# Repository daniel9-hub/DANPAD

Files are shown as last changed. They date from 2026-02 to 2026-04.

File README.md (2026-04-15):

# DANPAD
Hello, this is my submission for hackpad. I hope you'll like it :)
# Picture of the finished Hackpad


# Features
- 6 keys
- EC11 rotary encoder for volume adjusting
- 2 SK6812 MINI RGB LEDs
- a 3d printed case
# CAD Model
I made the model for the case in Onshape. It has 4 pieces: a bottom and mid plate(separated in case i needed to change
something so that i dont have to reprint the entire case), a top plate and a knob

Here is the case without electronics

# PCB
I made the pcb in KiCad. I used the image converter in KiCad for the pictures.
|Schematic|PCB|
|---|---|
|||
# Firmware
I wrote the code with KMK. The rotary encoder changes the volume and the keys do functions that i'm going to change according my needs.
# BOM
- 1x Seeed XIAO RP2040
- 6x MX-Style switches
- 6x Blank DSA keycaps
- 2x SK6812 MINI-E LEDs
- 1x EC11 Rotary encoder
- 4x M3x16mm screws
- 4x/8x M3x5mx4mm heatset inserts (i'm not sure how many i'll need)
- 1x 3d printed case
- 1x PCB
# Extra stuff
I might change the screw hole size on the case since i'm not sure how will the screws and heatset inserts fit. I also forgot to add a ground trace to the switches so I had to solder a wire to one of the switches right pin and connect it to the xiaos ground pin.

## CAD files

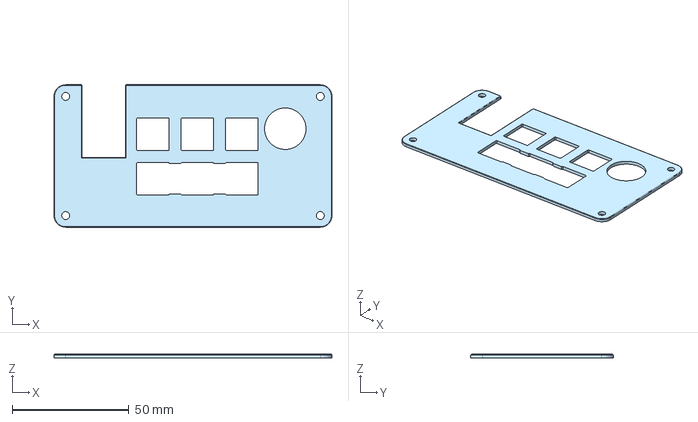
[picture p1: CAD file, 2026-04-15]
CAD/danpad top.step
119.0 x 61.0 x 1.50 mm

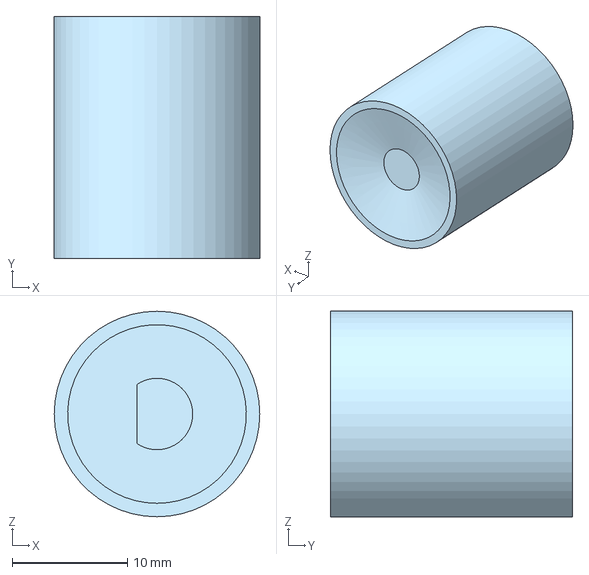
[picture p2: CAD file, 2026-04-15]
CAD/DANPAD WHEEL.step
17.8 x 21.0 x 17.8 mm

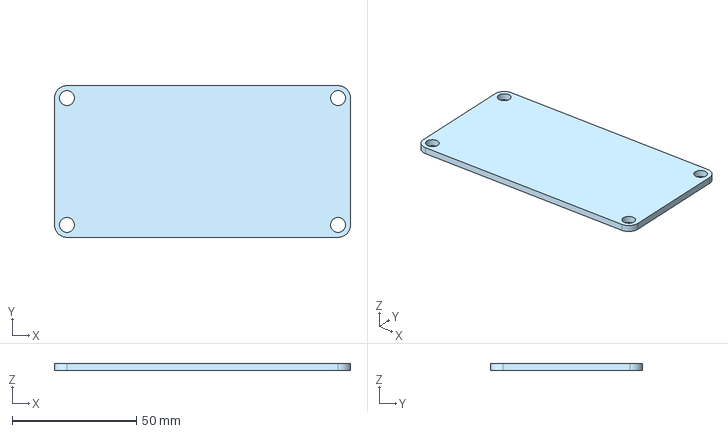
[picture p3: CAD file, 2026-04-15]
CAD/danpad bottom.step
119.0 x 61.0 x 3.00 mm

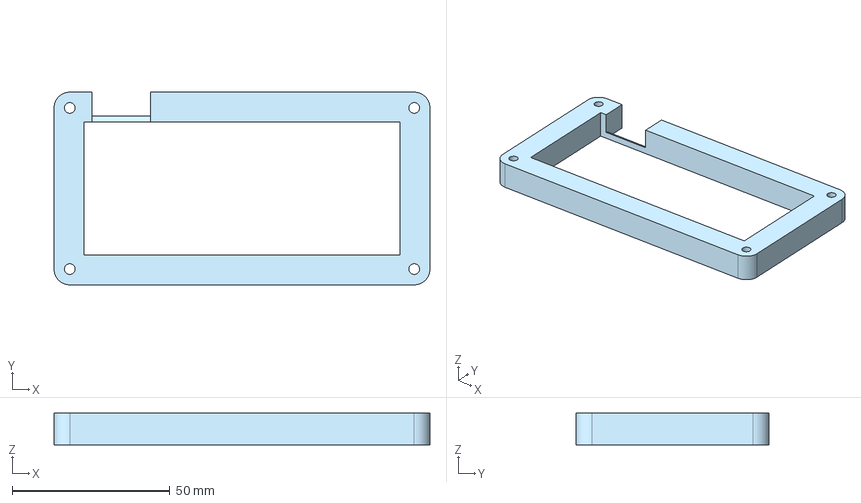
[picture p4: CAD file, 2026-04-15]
CAD/danpad middle.step
119.0 x 61.0 x 10.0 mm

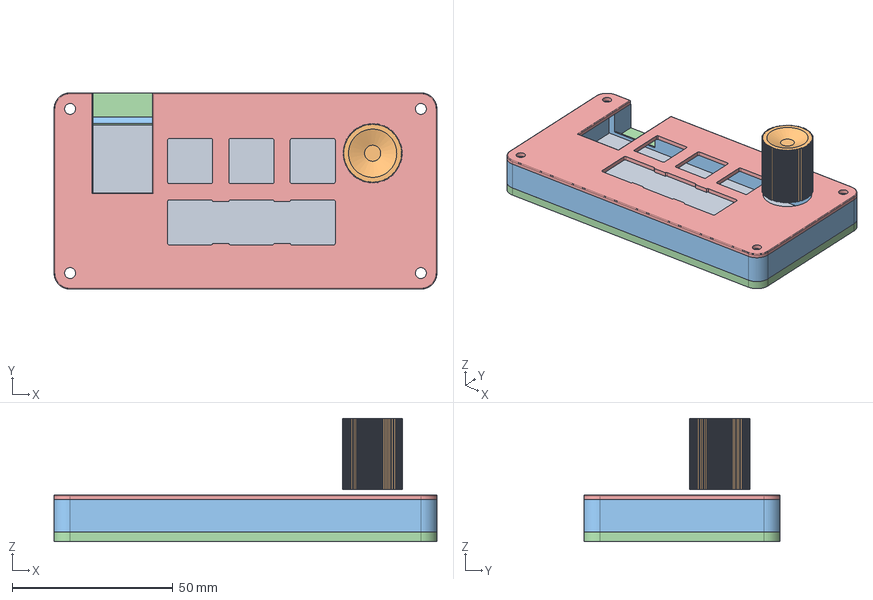
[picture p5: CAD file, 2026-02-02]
CAD/DANPAD hackpad.step
119.0 x 61.0 x 38.2 mm

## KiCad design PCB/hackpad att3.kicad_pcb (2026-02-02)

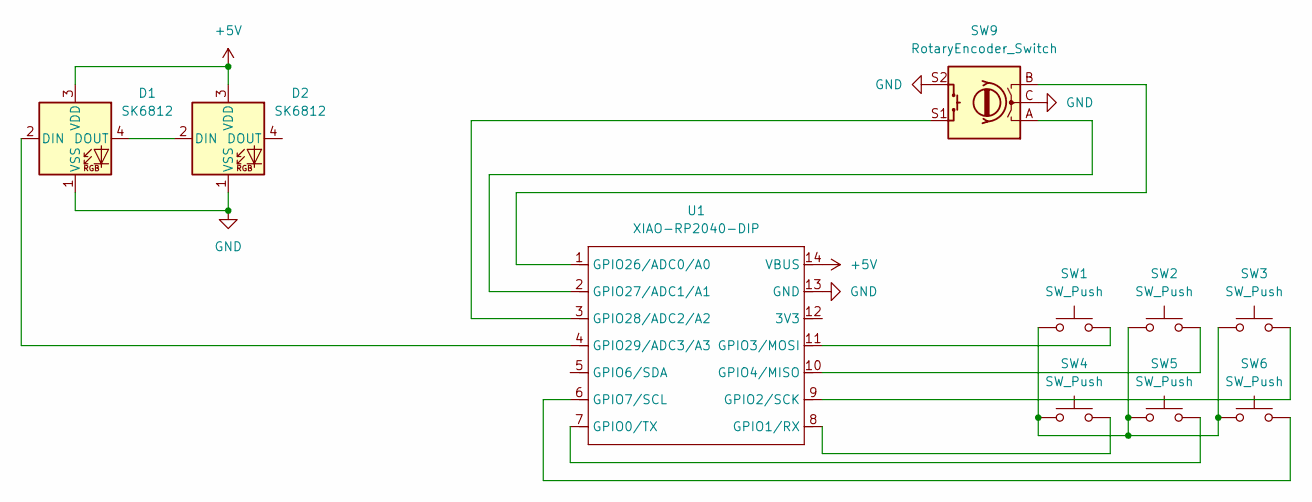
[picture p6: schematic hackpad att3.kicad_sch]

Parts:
D1, D2: SK6812; LED_SK6812MINI_PLCC4_3.5x3.5mm_P1.75mm
SW1, SW2, SW3, SW4, SW5, SW6: SW_Push; SW_Cherry_MX_1.00u_PCB
SW9: RotaryEncoder_Switch; RotaryEncoder_Alps_EC11E-Switch_Vertical_H20mm
U1: XIAO-RP2040-DIP

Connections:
+5V: D1.3 (VDD), D2.3 (VDD), U1.14 (VBUS)
GND: D1.1 (VSS), D2.1 (VSS), SW9.C, SW9.S2, U1.13 (GND)
unnamed: D1.2 (DIN), U1.4 (GPIO29/ADC3/A3)
unnamed: D1.4 (DOUT), D2.2 (DIN)
unnamed: SW1.1, SW2.1, SW3.1, SW4.1, SW5.1, SW6.1
unnamed: SW5.2, U1.7 (GPIO0/TX)
unnamed: SW4.2, U1.8 (GPIO1/RX)
unnamed: SW3.2, U1.9 (GPIO2/SCK)
unnamed: SW1.2, U1.11 (GPIO3/MOSI)
unnamed: SW2.2, U1.10 (GPIO4/MISO)
unnamed: SW6.2, U1.6 (GPIO7/SCL)
unnamed: SW9.B, U1.1 (GPIO26/ADC0/A0)
unnamed: SW9.A, U1.2 (GPIO27/ADC1/A1)
unnamed: SW9.S1, U1.3 (GPIO28/ADC2/A2)

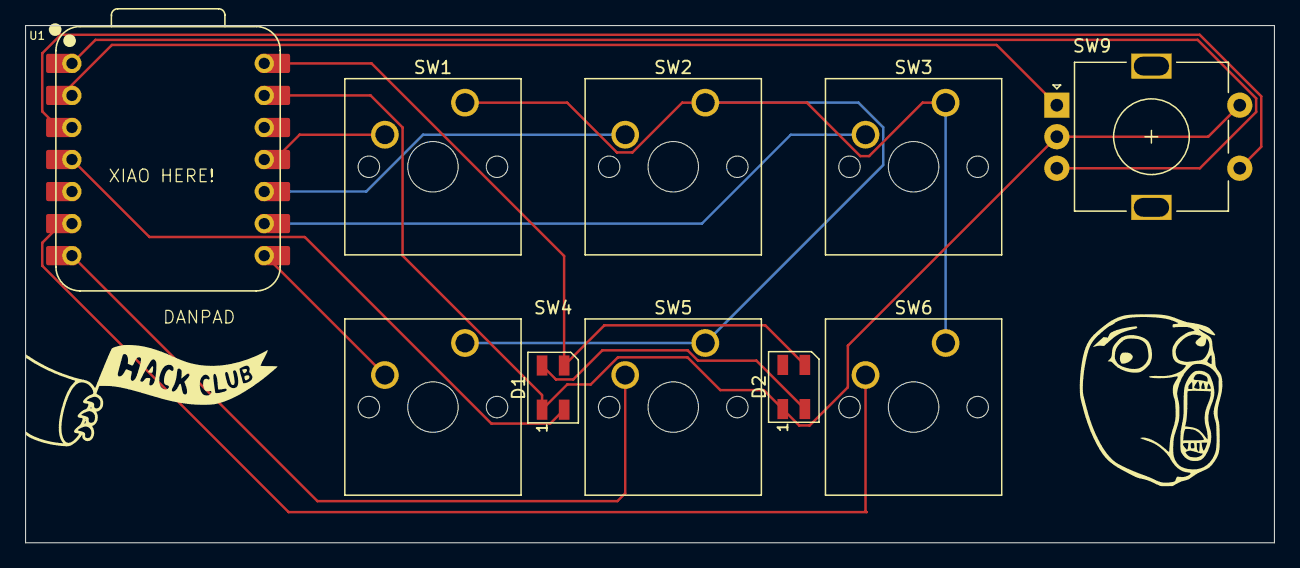
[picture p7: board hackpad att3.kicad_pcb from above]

Board: 2 copper layers, 99.0 x 41.0 mm, 10 parts (0 on the bottom side), 14 nets.

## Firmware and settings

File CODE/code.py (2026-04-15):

# main.py

print("Starting")

import board

from kmk.kmk_keyboard import KMKKeyboard
from kmk.keys import KC
from kmk.scanners.keypad import KeysScanner
from kmk.scanners import DiodeOrientation
from kmk.modules.macros import Macros
from kmk.modules.encoder import EncoderHandler
from kmk.extensions.rgb import RGB
keyboard = KMKKeyboard()
from kmk.extensions.media_keys import MediaKeys


macros = Macros()
keyboard.modules.append(macros)
encoder_handler = EncoderHandler()
keyboard.modules.append(encoder_handler)
keyboard.extensions.append(MediaKeys())



PINS = [board.GP3, board.GP4, board.GP2, board.GP1, board.GP0, board.GP7, board.GP28]


keyboard.matrix = KeysScanner(
    pins=PINS,
    value_when_pressed=False,
)



rgb = RGB(
    pixel_pin=board.GP29,
    num_pixels=2,
    rgb_order=(1, 0, 2),
    hue_default=100,
    sat_default=100,
    val_default=100,
    
)
keyboard.extensions.append(rgb)

encoder_handler.pins = ((board.GP27, board.GP26),) 


keyboard.keymap = [
    [KC.DELETE, KC.L, KC.SLASH, KC.C, KC.SPACE, KC.ENTER, KC.AUDIO_MUTE]
]

encoder_handler.map = [
    ((KC.AUDIO_VOL_UP, KC.AUDIO_VOL_DOWN),),
]

if __name__ == '__main__':
    keyboard.go()

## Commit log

2026-02-02 Add CAD folder
    [DANPAD hackpad.step]
2026-02-02 Add PCB folder
    [hackpad att3.kicad_pcb, hackpad att3.kicad_sch]
2026-04-15 Updated some stuff
    [DANPAD WHEEL.step, danpad bottom.step, danpad middle.step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]
